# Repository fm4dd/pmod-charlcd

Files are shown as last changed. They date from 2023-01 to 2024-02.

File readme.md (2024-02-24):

## CharLCD PMOD

### Description

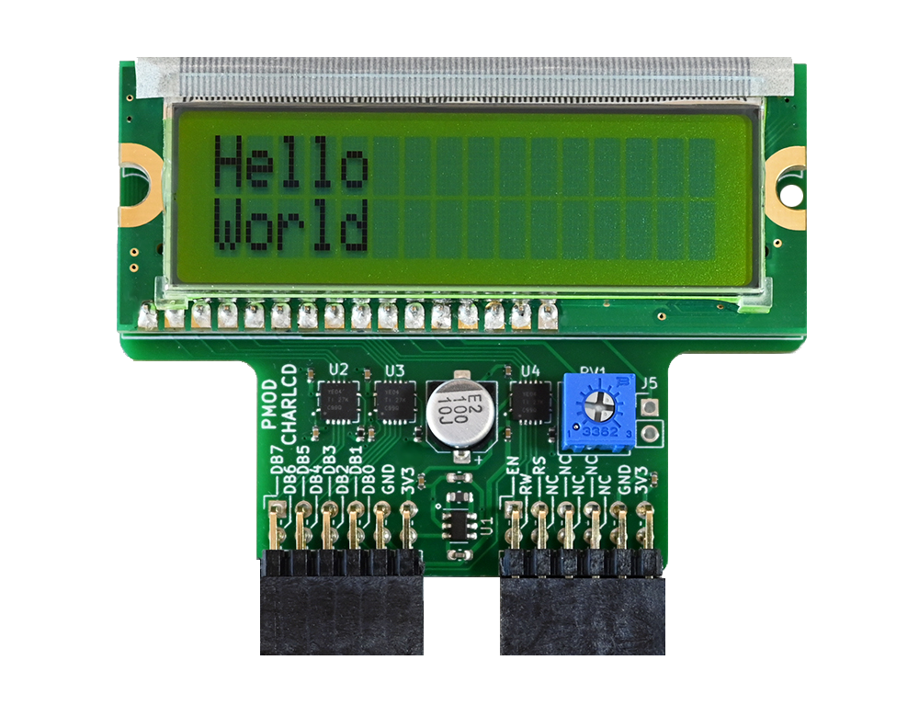
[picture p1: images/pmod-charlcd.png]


This PMOD interfaces a HD44780-compatible 5V character LCD module via two PMOD connectors. This design connects all 8 data signal lines, and allows to run the LCD in both 4-bit and 8-bit mode. The build-in level converter boosts the 3.3V PMOD power and signal levels to 5V. Its physical size matches LCD modules types such as the Sunlike HUOB-XA-G-G. The additional 7x2 socket can interface with LCD displays using the 7x2 dual-row connector type. The resistor RV1 controls the contrast.

http://fpga.fm4dd.com/

### Schematic
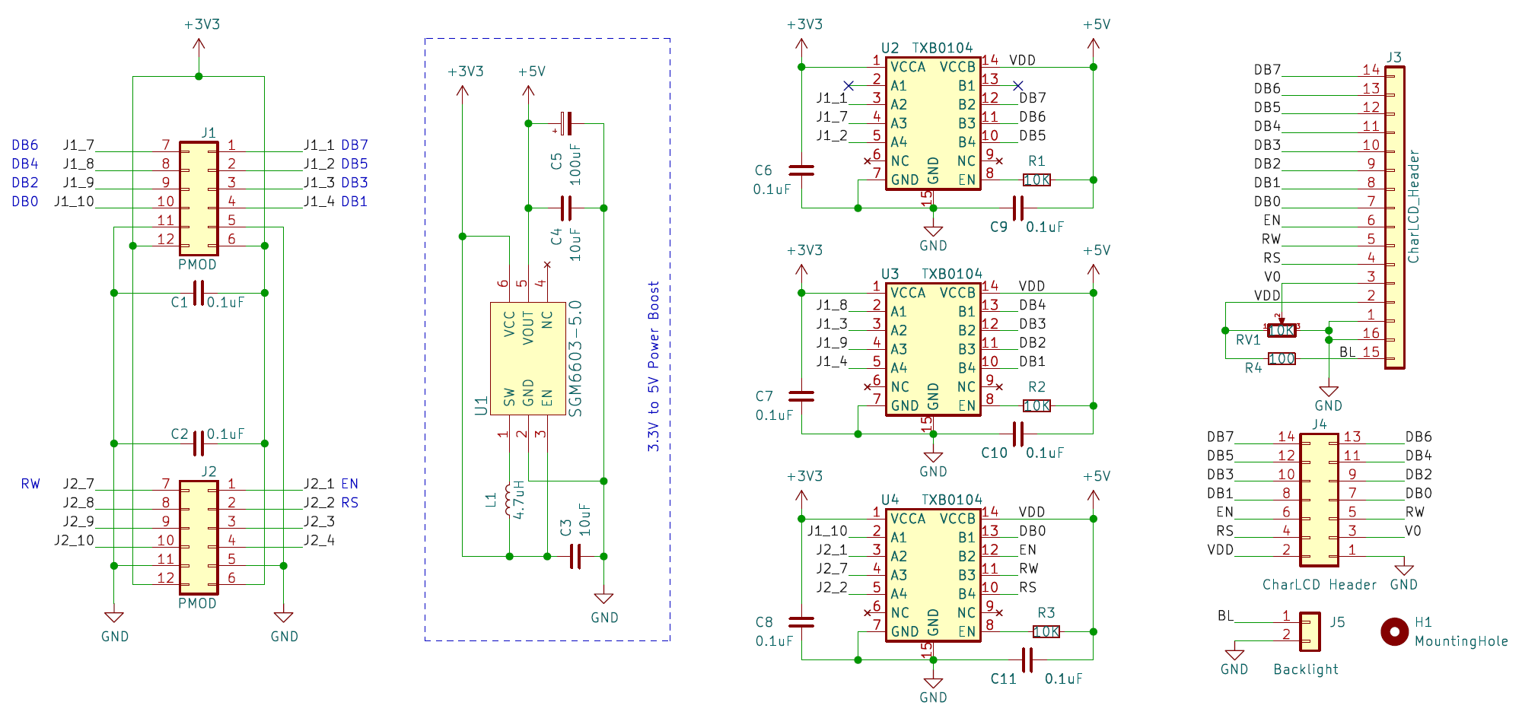
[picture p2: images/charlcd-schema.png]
CHARLCD PMOD Schematics


### PCB Gerber

| Version | Gerber | Schema |
|---|---|---|
| 1.0 |[20221207-pmod-charlcd-gerber.zip](fabfiles/v10/20221207-pmod-charlcd-gerber.zip) | [20221207-pmod-charlcd-schema.pdf](fabfiles/v10/20221207-pmod-charlcd-schema.pdf) |

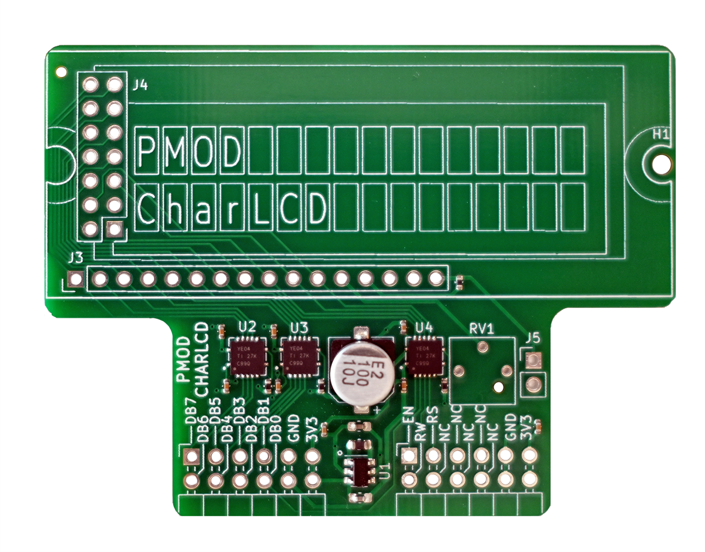
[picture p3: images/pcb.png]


### Pin Assignments

#### IceBreaker v1.0

 J21 |	Label |	Description   |	PMOD1A | J22 |	Label |	Description   | PMOD1B
-----|--------|---------------|--------|-----|--------|---------------|--------
1    |	d[7]  |	LCD Data-7    | 4      |1    |	en    |	LCD EN Signal | 43
2    |	d[5]  |	LCD Data-5    | 2      |2    |	rs    |	LCD RS Signal | 38
3    |	d[3]  |	LCD Data-3    | 47     |3    |	-     |	Not connected | 34
4    |  d[1]  |	LCD Data-1    | 45     |4    |  -     | Not connected | 31
7    |	d[6]  |	LCD Data-6    | 3      |7    |	rw    |	LCD RW Signal | 42
8    |	d[4]  |	LCD Data-4    | 48     |8    |	-     |	Not connected | 36
9    |  d[2]  |	LCD Data-2    |	46     |9    |  -     | Not connected | 32
10   |  d[0]  |	LCD Data-0    |	44     |10   |  -     |	Not connected | 28

### Code Examples

| Board | Description |
|---|---|
| [iCEBreaker](examples/icebreaker) | CharLCD Verilog demo for the iCEBreaker FPGA (Lattice ICE40UP5K)  |
| [Gatemate E1](examples/gatemate) | CharLCD Verilog demo for the Gatemate FPGA (Gatemate CCGM1A1)  |

### Board Pictures
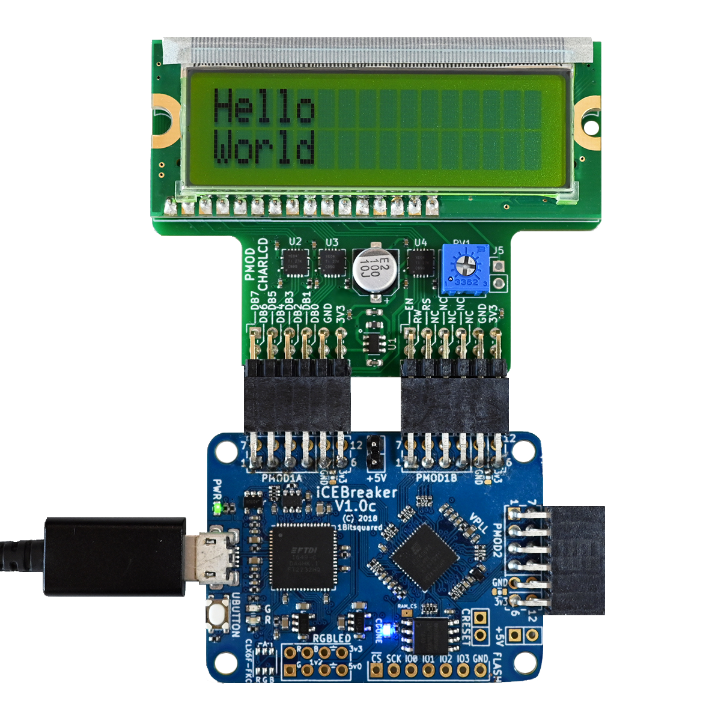
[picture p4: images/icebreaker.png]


CharLCD PMOD, connected to the iCEBreaker board.

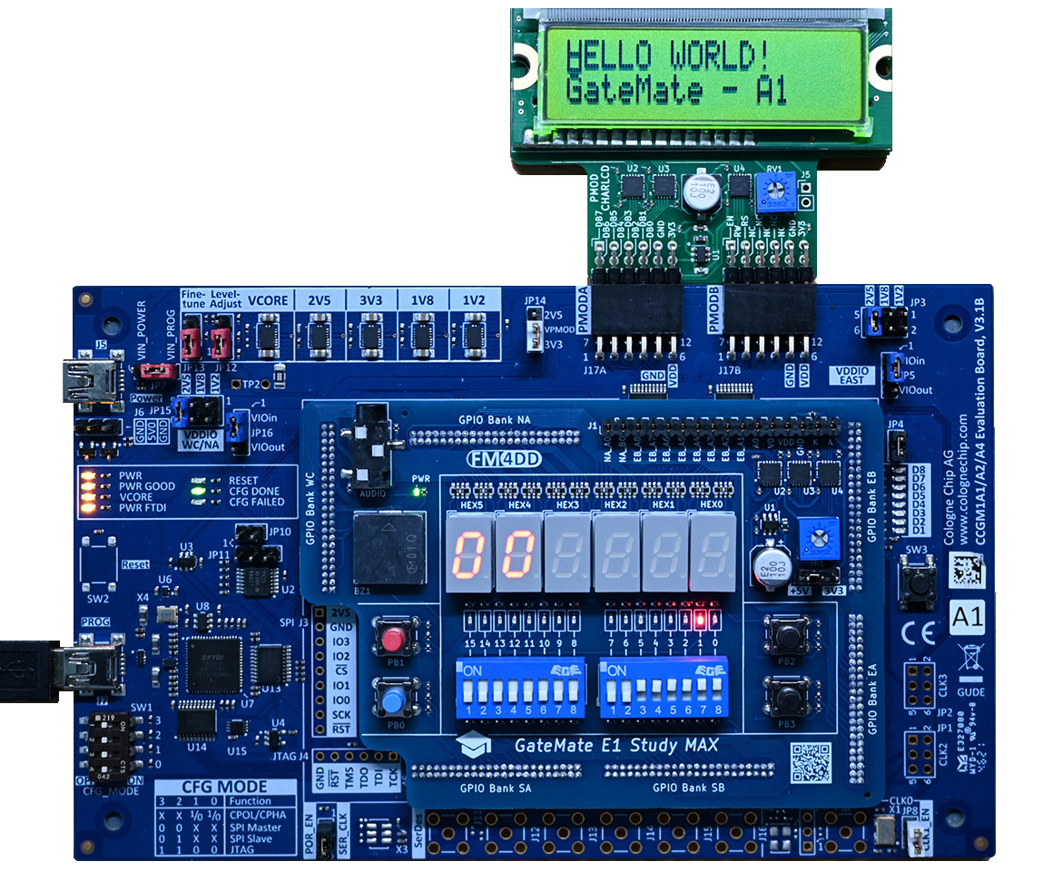
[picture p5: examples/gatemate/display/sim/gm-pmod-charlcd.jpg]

CharLCD PMOD, connected to the Gatemate E1 board.

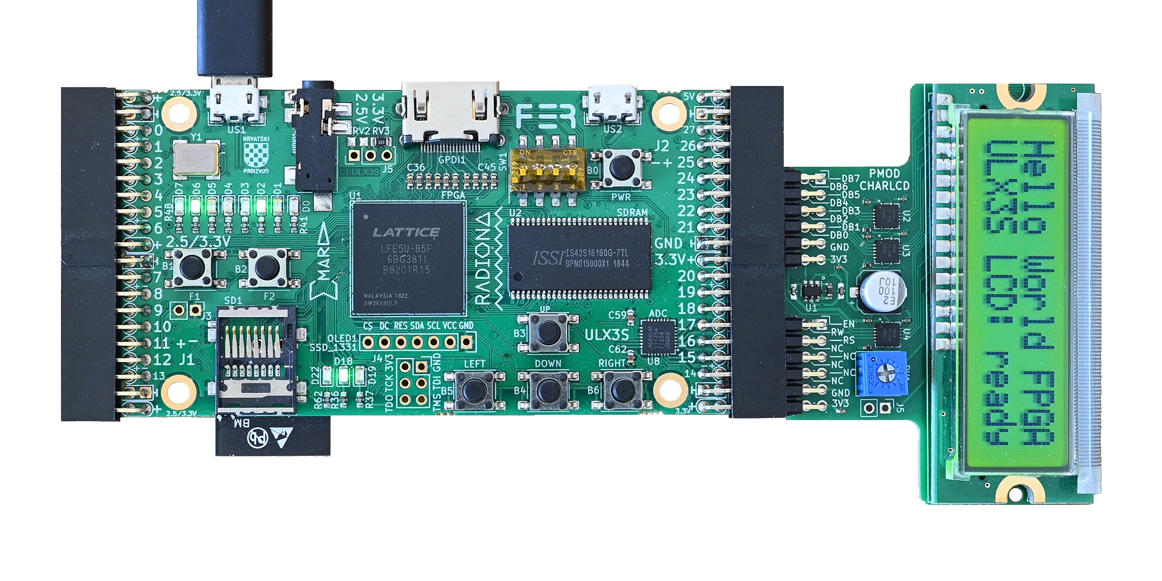
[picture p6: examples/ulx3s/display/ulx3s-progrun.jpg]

CharLCD PMOD, connected to the ULX3S board.

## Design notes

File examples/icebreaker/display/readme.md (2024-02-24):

## IceBreaker Character LCD Example "display"

This Verilog example program validates the function of an HD44780-compatible character LCD display,
using the PMOD character LCD PMOD module connected to the IceBreaker PMOD connectors 1A/1B.

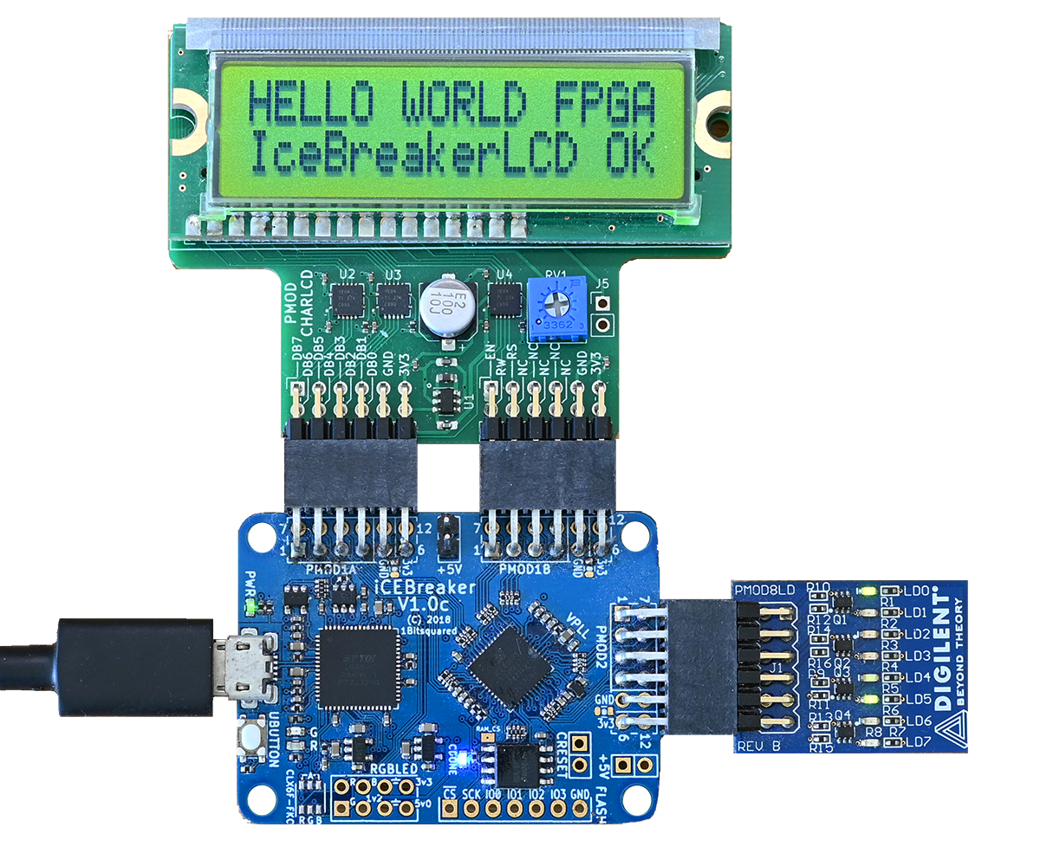
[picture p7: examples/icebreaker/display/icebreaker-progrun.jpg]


The IceBreaker push-button UBUTTON is used to toggle the display message on, and off (CLS). The LCD control line status is shown on  a (optional) Digilent PMOD 8LD, connected to PMOD2. The communication data is shown on LEDs D1..D6, while LEDs D7 and D8 show the UBUTTON toggle state.

### Pin Assignment



### Usage

```
fm@nuc7fpga:~/fpga/hardware/pmod-charlcd/examples/icebreaker/display$ make
/home/fm/oss-cad-suite/bin/yosys -p 'synth_ice40 -top display -json display.json' display.v debounce.v lcd_transmit.v
...
/home/fm/oss-cad-suite/bin/nextpnr-ice40 --package sg48 --up5k --asc display.asc --pcf icebreaker.pcf --json display.json --force
...
Info: Device utilisation:
Info: 	         ICESTORM_LC:   186/ 5280     3%
Info: 	        ICESTORM_RAM:     0/   30     0%
Info: 	               SB_IO:    21/   96    21%
Info: 	               SB_GB:     3/    8    37%
...
Info: Program finished normally.
/home/fm/oss-cad-suite/bin/icetime -d up5k -mtr display.rpt display.asc
// Reading input .asc file..
// Reading 5k chipdb file..
// Creating timing netlist..
// Timing estimate: 1000010.68 ns (0.00 MHz)
/home/fm/oss-cad-suite/bin/icepack display.asc display.bin
```

```
fm@nuc7fpga:~/fpga/hardware/pmod-charlcd/examples/icebreaker/display$ make prog
Programming to Flash:
/usr/bin/iceprog display.bin
init..
cdone: high
reset..
cdone: low
flash ID: 0xEF 0x40 0x18 0x00
file size: 104090
erase 64kB sector at 0x000000..
erase 64kB sector at 0x010000..
programming..
done.
reading..
VERIFY OK
cdone: high
Bye.
```

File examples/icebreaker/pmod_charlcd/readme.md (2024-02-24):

## IceBreaker Character LCD Example "pmod_charlcd"

This Verilog example program validates the function of an HD44780-compatible character LCD display.
The PMOD character LCD module from https://github.com/fm4dd/pmod-charlcd is connected to the
IceBreaker PMOD connectors 1A/1B.

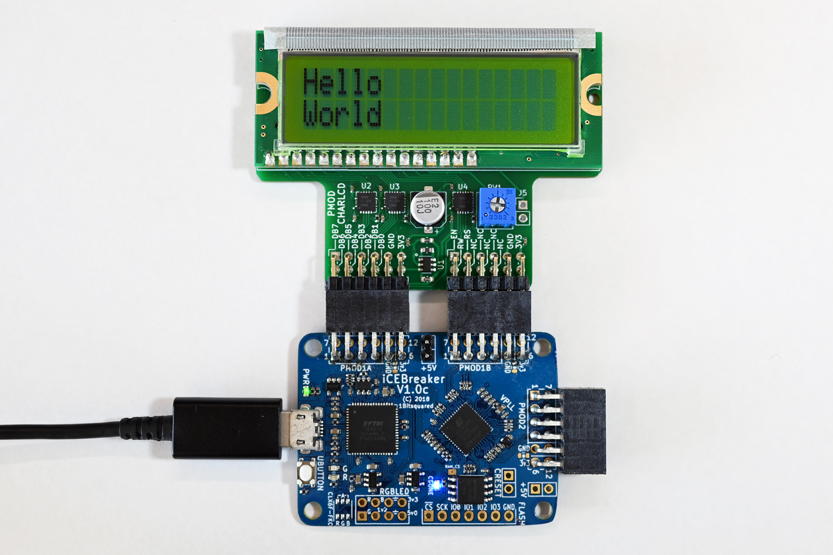
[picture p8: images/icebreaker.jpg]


The program displays the word "Hello" on line 1, and "World" on line 2.

### Usage

```
fm@nuc7fpga:~/fpga/hardware/pmod-charlcd/examples/icebreaker/pmod_charlcd$ make
/home/fm/oss-cad-suite/bin/yosys -p 'synth_ice40 -top pmod_charlcd -json pmod_charlcd.json' pmod_charlcd.v
...
Info: 	         ICESTORM_LC:   335/ 5280     6%
Info: 	        ICESTORM_RAM:     0/   30     0%
Info: 	               SB_IO:    13/   96    13%
Info: 	               SB_GB:     2/    8    25%
...
Info: Program finished normally.
/home/fm/oss-cad-suite/bin/icetime -d up5k -mtr pmod_charlcd.rpt pmod_charlcd.asc
// Reading input .asc file..
// Reading 5k chipdb file..
// Creating timing netlist..
// Timing estimate: 24.93 ns (40.11 MHz)
/home/fm/oss-cad-suite/bin/icepack pmod_charlcd.asc pmod_charlcd.bin
```

```
fm@nuc7fpga:~/fpga/hardware/pmod-charlcd/examples/icebreaker/pmod_charlcd$ make prog
Programming to Flash:
/home/fm/oss-cad-suite/bin/iceprog pmod_charlcd.bin
init..
cdone: high
reset..
cdone: low
flash ID: 0xEF 0x40 0x18 0x00
file size: 104090
erase 64kB sector at 0x000000..
erase 64kB sector at 0x010000..
programming..
done.
reading..
VERIFY OK
cdone: high
Bye.
```

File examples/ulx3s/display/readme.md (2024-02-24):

## ULX3S Character LCD Example "display"

This Verilog example program validates the function of an HD44780-compatible character LCD display.
I am using a PMOD character LCD module from https://github.com/fm4dd/pmod-charlcd, connected to the
ULX3S PMOD connectors on the right-side pin socket J2.



The ULX3S push-button F1 is used to toggle the display message on, and off (CLS).

The LCD control line status is shown on the onboard LEDs.
The communication data is shown on LEDs D0..D5, while LEDs D6 and D7 show the F1 toggle state.

### Pin Assignment



### Usage

```
fm@nuc7fpga:~/fpga/hardware/pmod-charlcd/examples/ulx3s/display$ make all
/home/fm/oss-cad-suite/bin/yosys -p 'synth_ecp5 -top display -noccu2 -nomux -nodram -json display.json' display.v debounce.v lcd_transmit.v
...
=== display ===

   Number of wires:                149
   Number of wire bits:            747
   Number of public wires:         149
   Number of public wire bits:     747
   Number of memories:               0
   Number of memory bits:            0
   Number of processes:              0
   Number of cells:                255
     LUT4                          179
     TRELLIS_FF                     76

...
/home/fm/oss-cad-suite/bin/nextpnr-ecp5 --85k --package CABGA381 --textcfg display.asc --lpf ulx3s.lpf --json display.json --force
...
Info: Device utilisation:
Info: 	          TRELLIS_IO:    21/  365     5%
Info: 	                DCCA:     1/   56     1%
...
Info: 	          TRELLIS_FF:    76/83640     0%
Info: 	        TRELLIS_COMB:   180/83640     0%
...
Info: Program finished normally.
/home/fm/oss-cad-suite/bin/ecppack display.asc --svf display.svf
/home/fm/oss-cad-suite/bin/ecppack display.asc --bit display.bit
```

```
fm@nuc7fpga:~/fpga/hardware/pmod-charlcd/examples/ulx3s/display$ make prog
Programming FPGA:
/home/fm/oss-cad-suite/bin/fujprog -b 115200 -j sram -T bit display.bit
ULX2S / ULX3S JTAG programmer v4.8 (git cc3ea93 built Nov 15 2022 18:03:02)
Copyright (C) Marko Zec, EMARD, gojimmypi, kost and contributors
Using USB cable: ULX3S FPGA 85K v3.0.8
Programming: 100%  
Completed in 44.65 seconds.
```

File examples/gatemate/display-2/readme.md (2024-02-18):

## Gatemate E1 Character LCD Example "display-2"

This Verilog example program validates the function of an HD44780-compatible character LCD display.
I am using a PMOD character LCD module from https://github.com/fm4dd/pmod-charlcd, connected to the
E1 PMOD connectors A/B.

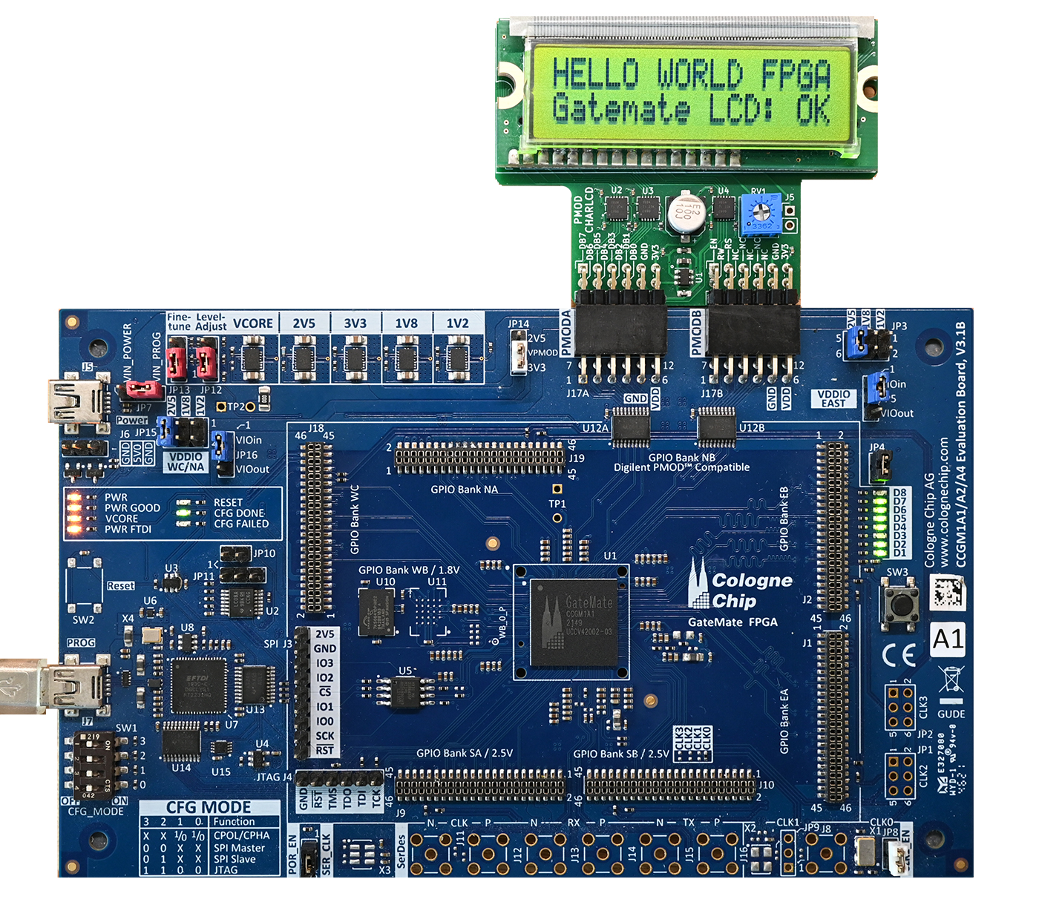
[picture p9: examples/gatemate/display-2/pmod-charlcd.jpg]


The E1 evaluation board switch SW3 is used to toggle the display message on, and off (CLS).

The LCD control line status is shown on the E1 onboard LEDs D1..D6, while LEDs D7 and D8 show the SW3 toggle state.

### Usage

```
fm@nuc7fpga:~/fpga/hardware/pmod-charlcd/examples/gatemate/display-2$ make all
/home/fm/cc-toolchain-linux/bin/yosys/yosys -ql log/synth.log -p 'read -sv src/debounce.v src/display.v src/lcd_transmit.v; synth_gatemate -top display -nomx8 -vlog net/display_synth.v'
/home/fm/cc-toolchain-linux/bin/p_r/p_r -i net/display_synth.v -o display -ccf src/gm-bare-pmod.ccf > log/impl.log
/home/fm/cc-toolchain-linux/bin/openFPGALoader/openFPGALoader  -b gatemate_evb_jtag display_00.cfg
Jtag frequency : requested 6.00MHz   -> real 6.00MHz  
Load SRAM via JTAG: [==================================================] 100.00%
Done
Wait for CFG_DONE DONE

```

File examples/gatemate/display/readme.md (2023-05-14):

## PMOD-CharLCD Example "display" on Gatemate-E1

This Verilog example program displays the string "Hello World! Gatemate A1" on the PMOD-CharLCD module equipped with a Sunlike 16x2 character LCD. The PMOD module is connected to a Gatemate E1 board through PMOD connectors PMODA (J17A) and PMODB (J17B). The serial clock is derived from the 10MHz system clock of the evaluation board.

### Usage

```
fm@nuc7vm2204:~/fpga/hardware/pmod-charlcd/examples/gatemate/display$ make all
/home/fm/cc-toolchain-linux/bin/yosys/yosys -ql log/synth.log -p 'read -sv src/debounce.v src/display.v src/hexdigit.v src/lcd_transmit.v; synth_gatemate -top display -nomx8 -vlog net/display_synth.v'
/home/fm/cc-toolchain-linux/bin/p_r/p_r -i net/display_synth.v -o display -ccf ../gatemate.ccf > log/impl.log
/usr/local/bin/openFPGALoader  -b gatemate_evb_jtag display_00.cfg
Jtag frequency : requested 6.00MHz   -> real 6.00MHz
Load SRAM via JTAG: [==================================================] 100.00%
Done
Wait for CFG_DONE DONE
```

### Example



The program, executed under a Digilent Analog Discovery 2 logic analyzer:

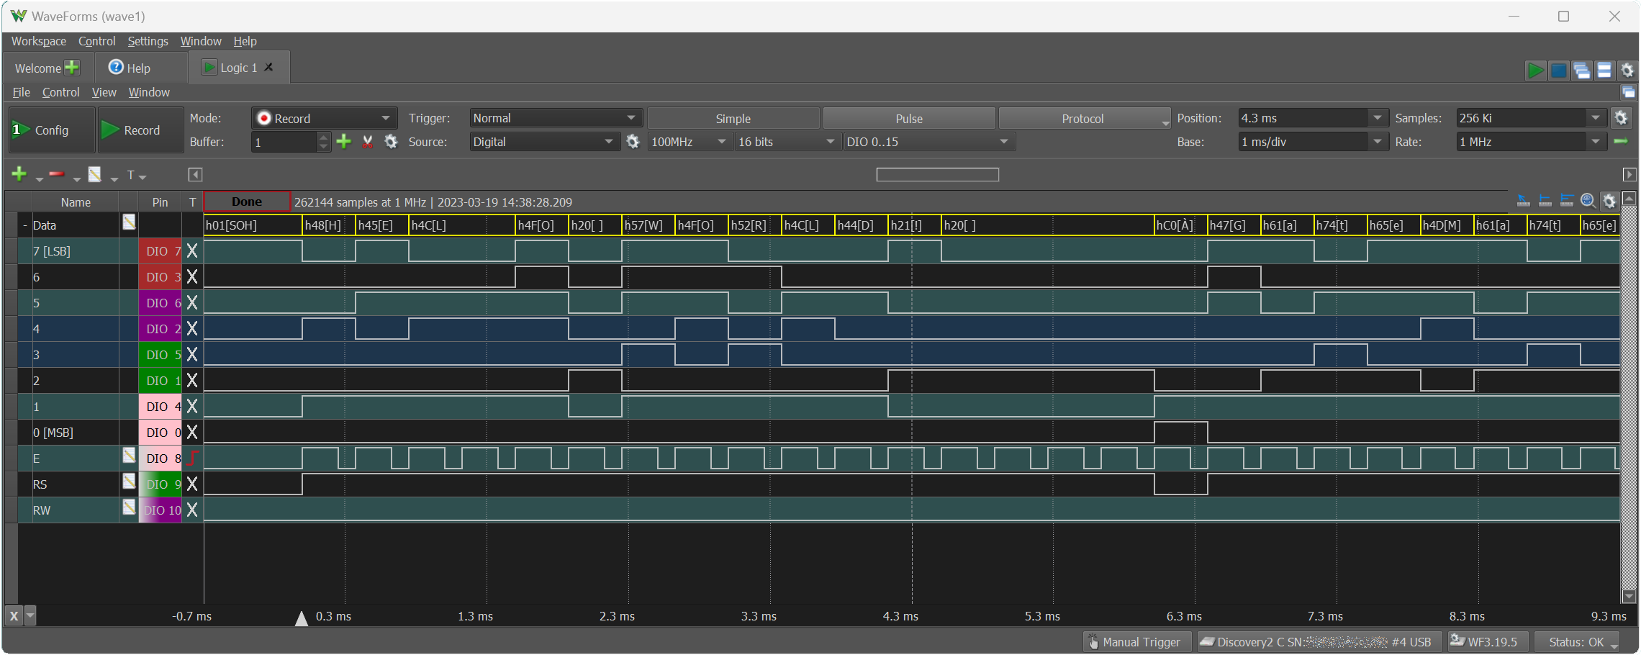
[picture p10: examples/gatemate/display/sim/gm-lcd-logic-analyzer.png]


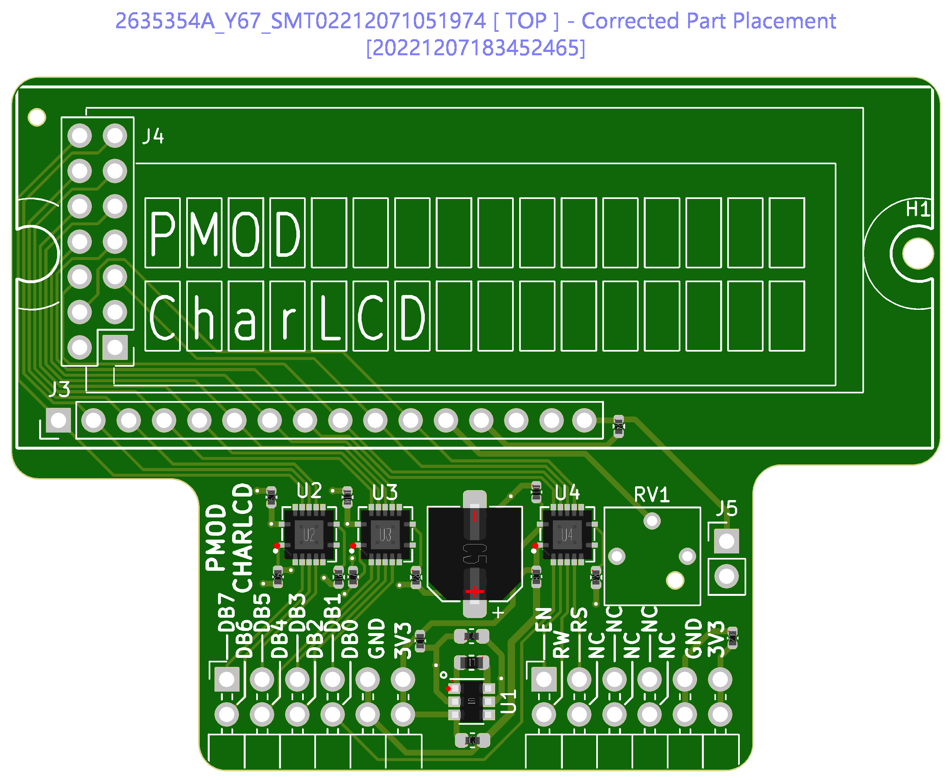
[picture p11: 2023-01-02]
images/fab-placement.png

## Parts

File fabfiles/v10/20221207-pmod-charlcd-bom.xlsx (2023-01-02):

Comment | Designator | Footprint | JLCPCB Part #（optional）
0.1u C0402C103K4RECAUTO | C1,C2,C6,C7,C8,C9,C10,C11 | C_0402_1005Metric | C1525
10uF 0402CG150J500NT | C3,C4 | C_0402_1005Metric | C30274
100uF | C5 | CP_Elec_6.3x5.3 | C134749
4.7uH | L1 | L_0603_1608Metric | C1034
SGM6603-5.0 | U1 | SOT-23-6 | C79689
TXB0104 | U2,U3,U4 | S-PVQFN-N14-1EP_3.65x3.65_P0.5_EP2.05x2.05 | C400708
10K | R1,R2,R3 | R_0402_1005Metric | C25744
100 | R4 | R_0402_1005Metric | C25076

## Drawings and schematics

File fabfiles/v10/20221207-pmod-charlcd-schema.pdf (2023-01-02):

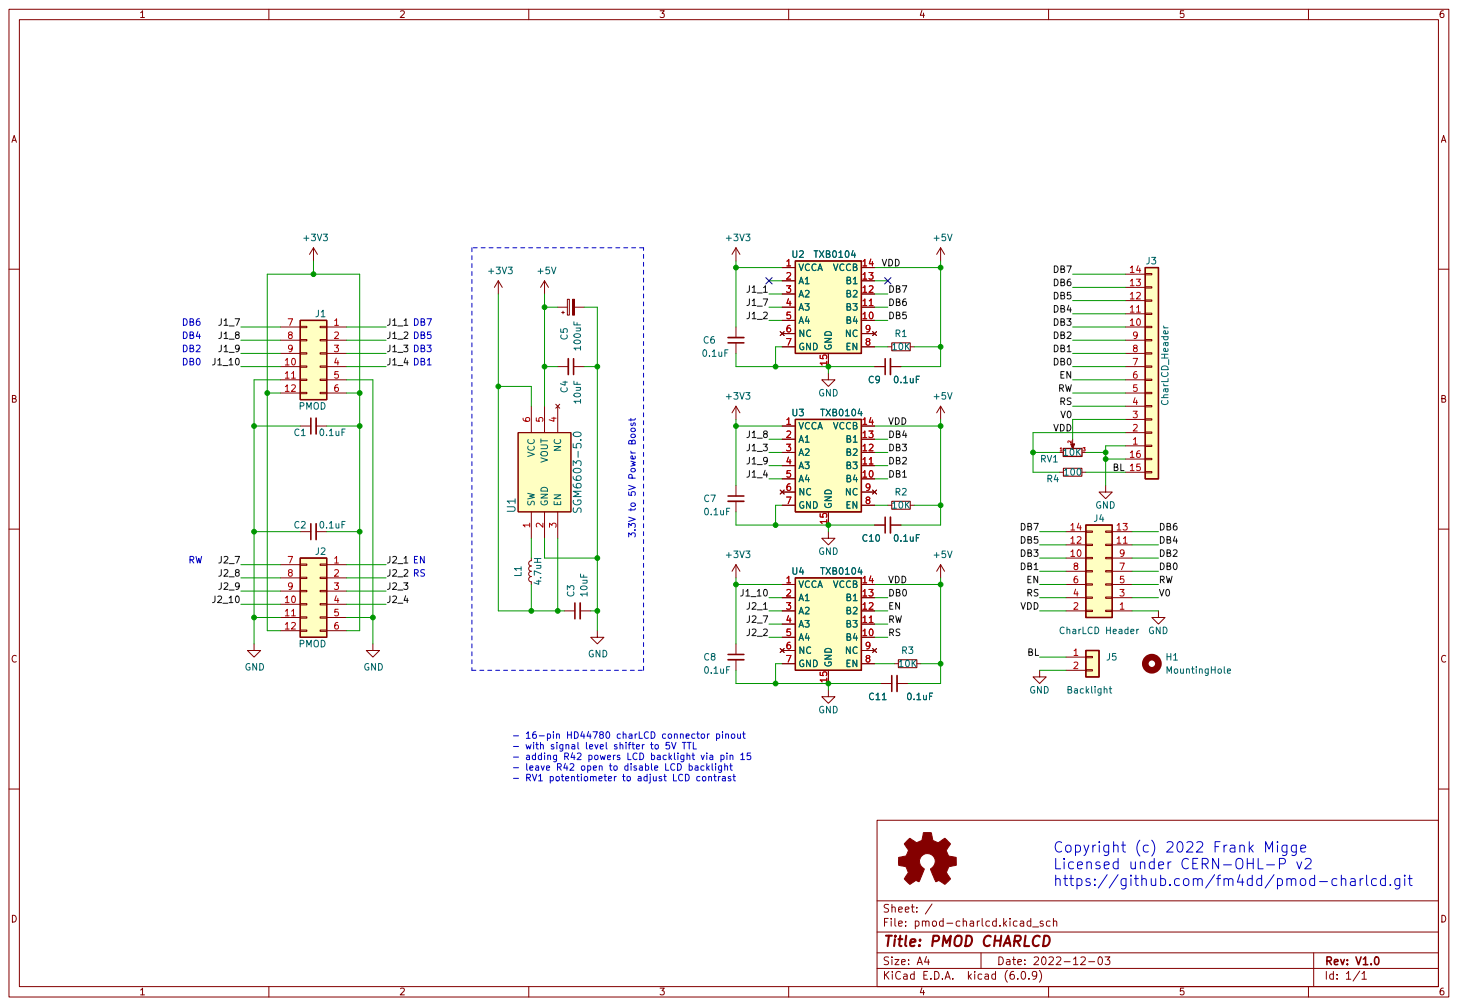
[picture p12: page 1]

- 16-pin HD44780 charLCD connector pinout
- with signal level shifter to 5V TTL
- adding R42 powers LCD backlight via pin 15
- leave R42 open to disable LCD backlight

Copyright (c) 2022 Frank Migge
Licensed under CERN-OHL-P v2
https://github.com/fm4dd/pmod-charlcd.git

File: pmod-charlcd.kicad_sch Sheet: /
Id: 1/1 Title: PMOD CHARLCD

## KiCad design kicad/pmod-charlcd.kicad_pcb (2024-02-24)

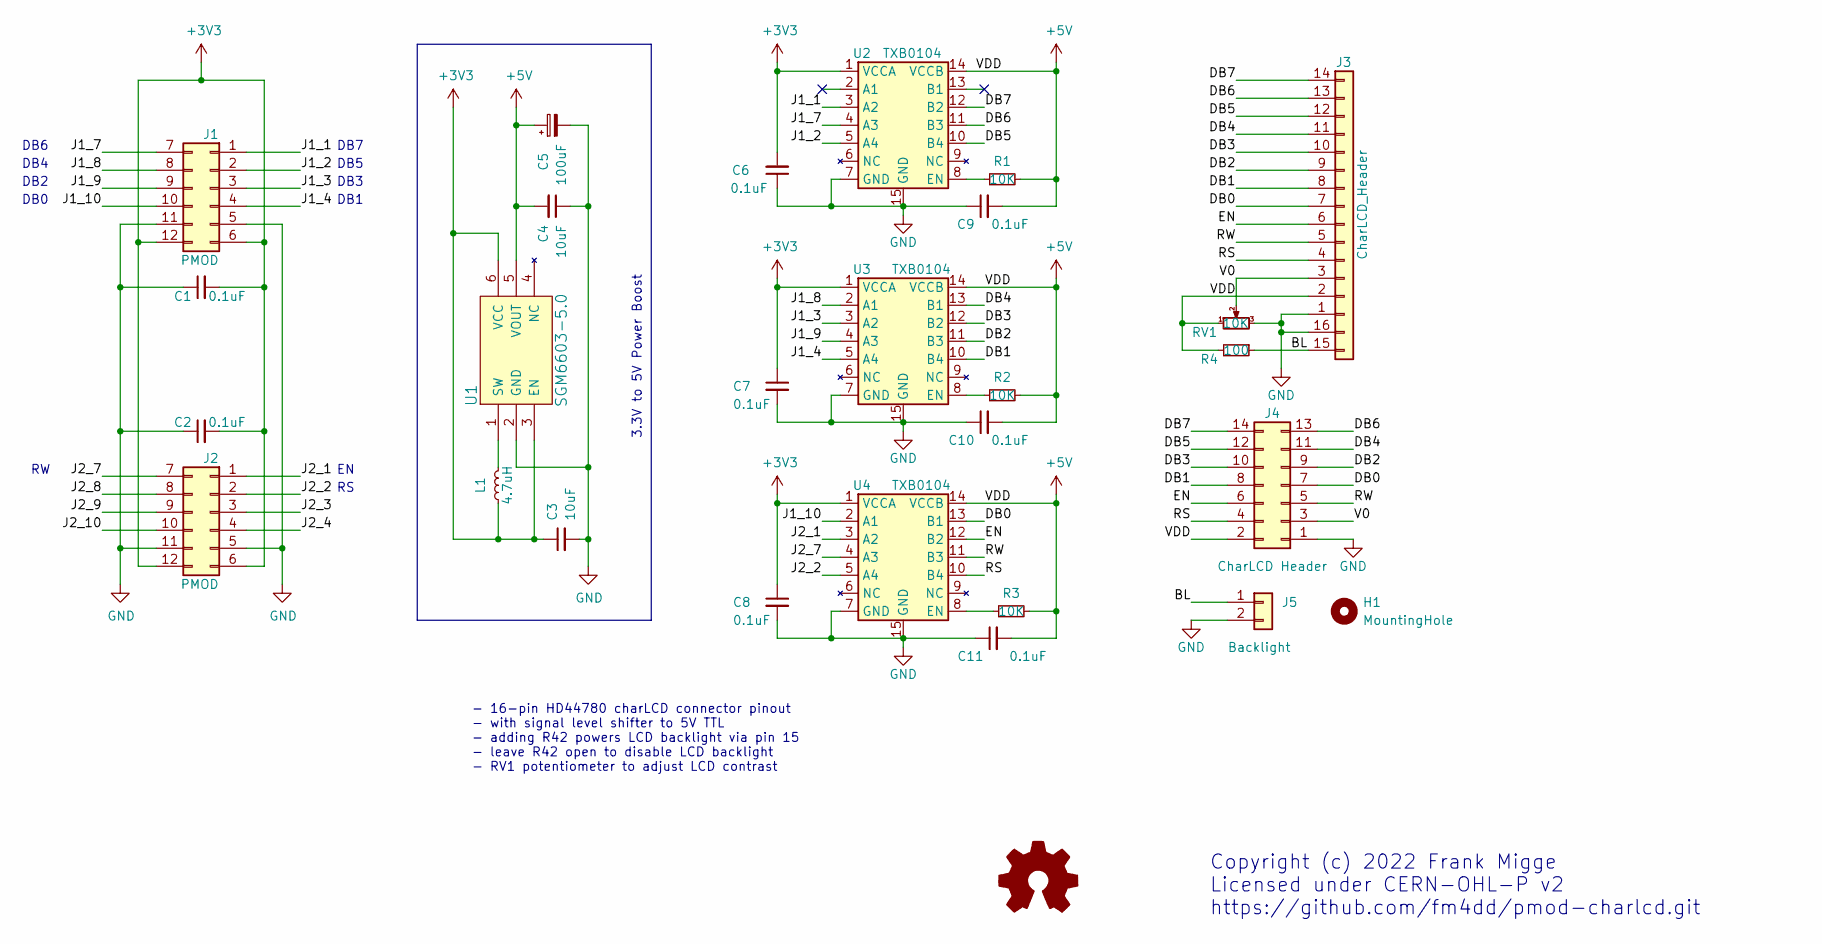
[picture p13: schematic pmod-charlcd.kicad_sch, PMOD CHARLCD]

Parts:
C1, C2, C6, C7, C8, C9, C10, C11: 0.1uF; C_0402_1005Metric
C3, C4: 10uF; C_0603_1608Metric
C5: 100uF; CP_Elec_6.3x5.4
H1: MountingHole; MountingHole_2.1mm
J1, J2: PMOD; PMODHeader_2x06_P2.54mm_Horizontal
J3: CharLCD_Header; CharLCD Header HUOB-XA-G-G
J4: CharLCD Header; CharLCD_PinSocket_2x07
J5: Backlight; PinHeader_1x02_P2.54mm_Vertical
L1: 4.7uH; L_0603_1608Metric
R1, R2, R3: 10K; R_0402_1005Metric
R4: 100; R_0402_1005Metric
RV1: 10K; Potentiometer_Bourns_3362P_Vertical
U1: SGM6603-5.0; SOT-23-6
U2, U3, U4: TXB0104; S-PVQFN-N14-1EP_3.65x3.65_P0.5_EP2.05x2.05

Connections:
+3V3: C1.2, C2.2, C3.1, C6.2, C7.1, C8.1, J1.6, J1.12, J2.6, J2.12, L1.1, U1.3 (EN), U1.6 (VCC), U2.1 (VCCA), U3.1 (VCCA), U4.1 (VCCA)
+5V: C4.2, C5.1, C9.2, C10.2, C11.2, J3.2, J4.2, R1.2, R2.2, R3.2, R4.2, RV1.1, U1.5 (VOUT), U2.14 (VCCB), U3.14 (VCCB), U4.14 (VCCB)
/BL: J3.15, J5.1, R4.1
/DB0: J3.7, J4.7, U4.13 (B1)
/DB1: J3.8, J4.8, U3.10 (B4)
/DB2: J3.9, J4.9, U3.11 (B3)
/DB3: J3.10, J4.10, U3.12 (B2)
/DB4: J3.11, J4.11, U3.13 (B1)
/DB5: J3.12, J4.12, U2.10 (B4)
/DB6: J3.13, J4.13, U2.11 (B3)
/DB7: J3.14, J4.14, U2.12 (B2)
/EN: J3.6, J4.6, U4.12 (B2)
/J1_1: J1.1, U2.3 (A2)
/J1_2: J1.2, U2.5 (A4)
/J1_3: J1.3, U3.3 (A2)
/J1_4: J1.4, U3.5 (A4)
/J1_7: J1.7, U2.4 (A3)
/J1_8: J1.8, U3.2 (A1)
/J1_9: J1.9, U3.4 (A3)
/J1_10: J1.10, U4.2 (A1)
/J2_1: J2.1, U4.3 (A2)
/J2_2: J2.2, U4.5 (A4)
/J2_3: J2.3
/J2_4: J2.4
/J2_7: J2.7, U4.4 (A3)
/J2_8: J2.8
/J2_9: J2.9
/J2_10: J2.10
/RS: J3.4, J4.4, U4.10 (B4)
/RW: J3.5, J4.5, U4.11 (B3)
/V0: J3.3, J4.3, RV1.2
GND: C1.1, C2.1, C3.2, C4.1, C5.2, C6.1, C7.2, C8.2, C9.1, C10.1, C11.1, J1.5, J1.11, J2.5, J2.11, J3.1, J3.16, J4.1, J5.2, RV1.3, U1.2 (GND), U2.7 (GND), U2.15 (GND), U3.7 (GND), U3.15 (GND), U4.7 (GND), U4.15 (GND)
unnamed: L1.2, U1.1 (SW)
unnamed: R1.1, U2.8 (EN)
unnamed: R2.1, U3.8 (EN)
unnamed: R3.1, U4.8 (EN)

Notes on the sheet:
DB0
DB2
DB1
DB7
Copyright (c) 2022 Frank Migge Licensed under CERN-OHL-P v2 https://github.com/fm4dd/pmod-charlcd.git
- 16-pin HD44780 charLCD connector pinout - with signal level shifter to 5V TTL - adding R42 powers LCD backlight via pin 15 - leave R42 open to disable LCD backlight - RV1 potentiometer to adjust LCD contrast
3.3V to 5V Power Boost
DB3
DB6
DB4
DB5

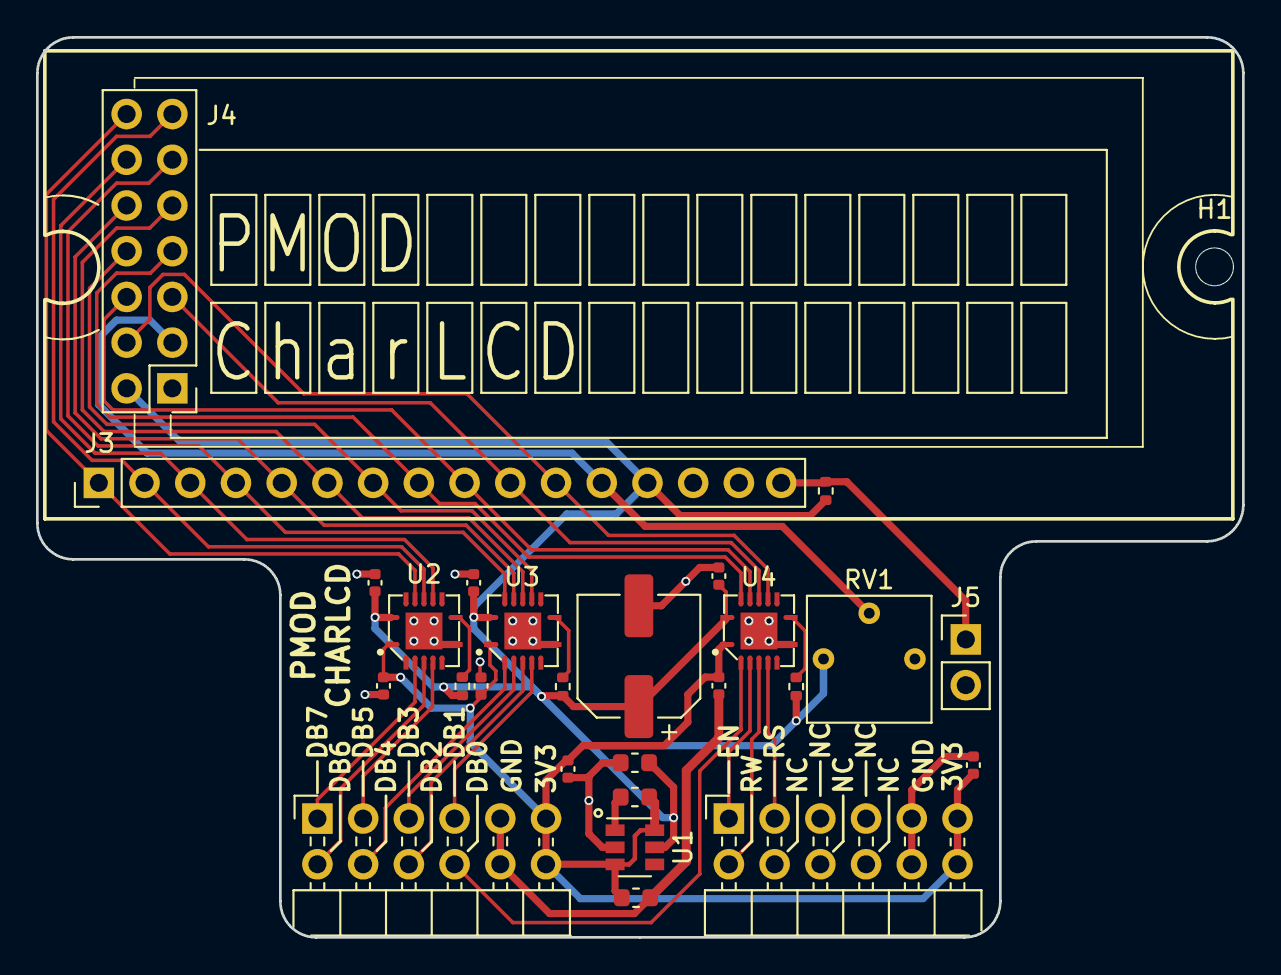
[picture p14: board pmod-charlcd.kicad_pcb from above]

Board: 2 copper layers, 67.0 x 50.0 mm, 27 parts (0 on the bottom side), 31 nets.

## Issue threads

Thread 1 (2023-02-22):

Backlight resistor R4 to strong for HUOB-XA-G-G

fm4dd, 2023-02-22:
With R4 at 100 Ohm, the HUOB-XA-G-G LCD backlight illumination is weak. While for most other character LCD, a 100 Ohm backlight resistor is the best value, for HUOB-XA-G-G modules it is slightly too strong and can be reduced or even eliminated. Should add a resistor bypass solder bridge in newer designs.

Closed 2023-02-22.

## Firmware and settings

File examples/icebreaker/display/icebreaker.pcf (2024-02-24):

# 12 MHz clock
set_io -nowarn clk        35

# RS232
set_io -nowarn RX          6
set_io -nowarn TX          9

# LEDs and Button
set_io -nowarn rst        10
set_io -nowarn LEDR_N     11
set_io -nowarn LEDG_N     37

# RGB LED Driver
set_io -nowarn LED_RED_N  39
set_io -nowarn LED_GRN_N  40
set_io -nowarn LED_BLU_N  41

# SPI Flash
set_io -nowarn FLASH_SCK  15
set_io -nowarn FLASH_SSB  16
set_io -nowarn FLASH_IO0  14
set_io -nowarn FLASH_IO1  17
set_io -nowarn FLASH_IO2  12
set_io -nowarn FLASH_IO3  13

# PMOD 1A
set_io -nowarn lcd_d[7]   4
set_io -nowarn lcd_d[5]   2
set_io -nowarn lcd_d[3]  47
set_io -nowarn lcd_d[1]  45
set_io -nowarn lcd_d[6]   3
set_io -nowarn lcd_d[4]  48
set_io -nowarn lcd_d[2]  46
set_io -nowarn lcd_d[0]  44

# PMOD 1B
set_io -nowarn lcd_en     43
set_io -nowarn lcd_rs     38
set_io -nowarn lcd_rw     42

# PMOD 2
set_io -nowarn led[7]     27
set_io -nowarn led[6]     25
set_io -nowarn led[5]     21
set_io -nowarn led[4]     19
set_io -nowarn led[3]     26
set_io -nowarn led[2]     23
set_io -nowarn led[1]     20
set_io -nowarn led[0]     18

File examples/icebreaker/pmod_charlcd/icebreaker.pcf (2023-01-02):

# 12 MHz clock
set_io -nowarn clk        35

# RS232
set_io -nowarn RX          6
set_io -nowarn TX          9

# LEDs and Button
set_io -nowarn push_button        10
set_io -nowarn LEDR_N     11
set_io -nowarn LEDG_N     37

# RGB LED Driver
set_io -nowarn LED_RED_N  39
set_io -nowarn LED_GRN_N  40
set_io -nowarn LED_BLU_N  41

# SPI Flash
set_io -nowarn FLASH_SCK  15
set_io -nowarn FLASH_SSB  16
set_io -nowarn FLASH_IO0  14
set_io -nowarn FLASH_IO1  17
set_io -nowarn FLASH_IO2  12
set_io -nowarn FLASH_IO3  13

# PMOD 1A
set_io -nowarn d[7]   4
set_io -nowarn d[5]   2
set_io -nowarn d[3]  47
set_io -nowarn d[1]  45
set_io -nowarn d[6]   3
set_io -nowarn d[4]  48
set_io -nowarn d[2]  46
set_io -nowarn d[0]  44

# PMOD 1B
set_io -nowarn en     43
set_io -nowarn rs     38
set_io -nowarn rw     42

# PMOD 2
#set_io -nowarn P2_1       27
#set_io -nowarn P2_2       25
#set_io -nowarn P2_3       21
#set_io -nowarn P2_4       19
#set_io -nowarn P2_7       26
#set_io -nowarn P2_8       23
#set_io -nowarn P2_9       20
#set_io -nowarn P2_10      18

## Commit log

2023-01-02 repo init
    [20221207-pmod-charlcd-bom.xlsx, pmod-charlcd.kicad_pcb, pmod-charlcd.kicad_sch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]
2023-02-22 fix assignment table pin rw
2024-02-24 add ULX3S example
    [pmod-charlcd.kicad_pcb]

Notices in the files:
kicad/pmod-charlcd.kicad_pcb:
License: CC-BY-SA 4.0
